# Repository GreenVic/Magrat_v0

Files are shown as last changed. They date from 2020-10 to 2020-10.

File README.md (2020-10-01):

# "Magrat" STM32H7 Board

NOTE: This is an early revision of a board which I am in the process of revising. I'm publishing the design files for the sake of sharing now that I've tested many (but not all) of the board's main features, but there are plenty of improvements which should be made, and you should not treat this as a solid reference implementation or a finalized production-ready design.

In particular, the SDRAM traces need better length- and impedance-matching; they seem to work up to 80-100MHz, but the chips are rated for 166MHz. The BOOT0 and JTAG signals should also be broken out, because the STM32H7's myriad clock domains seem to cause minor issues with SWD debugging.

With those disclaimers out of the way, "Magrat" is an STM32H7 board which aims to integrate enough external memory to run a minimal Linux system in a low-cost format. It is designed for single-sided PCA with parts from the LCSC catalog, so you should be able to order it 'as is' from JLCPCB when / if the parts are in stock.

This board should be able to run a mainline Linux kernel, and I've gotten one booting, but I'm still working on bringing up a fully-functional system, and I'm not quite sure that the microSD card socket works yet.

(TODO: add generated gerbers, BoM, pick-and-place files)

# Board Renders:

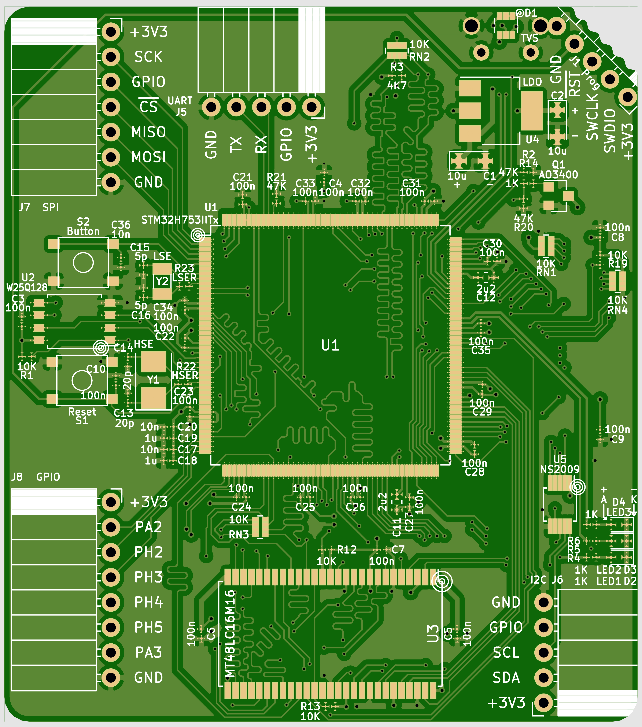
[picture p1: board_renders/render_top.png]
Board Top

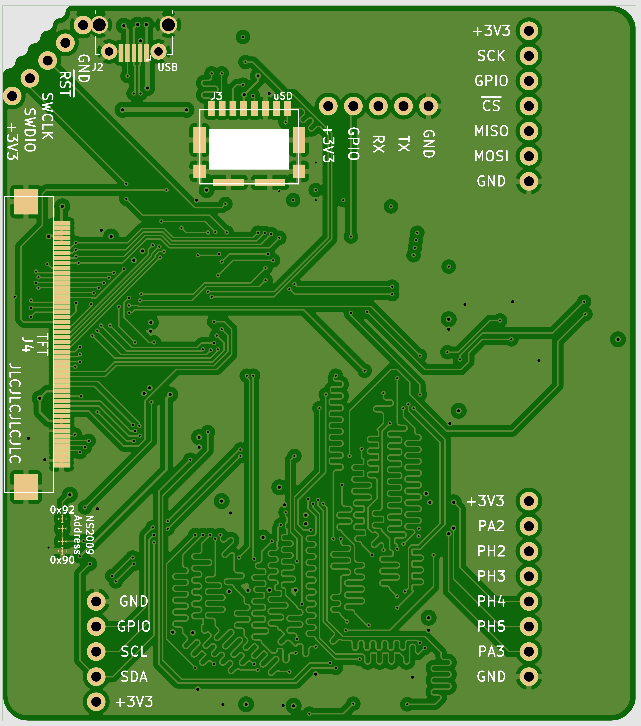
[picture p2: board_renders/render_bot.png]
Board Bottom


## Features

* STM32H7x3II: Cortex-M7, 480MHz, 2MiB Flash, 1MiB RAM

* 32MiB SDRAM

* 16MiB Quad-SPI Flash

* 50-pin ILI9341 display connector (untested)

* USB full-speed (untested)

* microSD card socket (untested)

* UART, SPI, I2C headers.

## (TODO: more explanation)

Test programs and a bit more information can be found in the `firmware/` directory.

They're a little rough-around-the-edges right now, because I haven't had these boards for long and it's my first time using an STM32H7 chip.

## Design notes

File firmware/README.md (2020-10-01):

# "Magrat" Board Test Programs

## Overview

These are a few basic test programs to communicate with the devices included on a first-revision STM32 SBC that I call a "Magrat".

I'm already planning a second revision with a few improvements:

* Better high-speed bus design. The 166-MHz SDRAM works, but it can't operate faster than 80MHz with the current design.
* Break out all of the JTAG pins, and BOOT0. SWD is not the best option for STM32H7 chips.
* Unify GPIOs into one or two headers.

The board includes:

* An STM32H743II or STM32H753II microcontroller
* 32MiB of SDRAM
* 16MiB of QSPI Flash
* microSD card socket
* 3 LEDs
* 1 button
* microUSB-B socket
* 50-pin FPC connector for an ILI9341 display
* NS2009 touch screen interface

And it has the following GPIO connectors:

* SPI
* UART
* I2C
* SWD
* 6 generic I/O pins

You can find the board design files in [TODO]. There is a KiCAD project, and a .zip archive containing PCB/PCA files in a format that JLCPCB (and probably other web-based PCA services) should accept.

Currently, the following tests are provided:

* leds\_test: Toggle the on-board LEDs.
* button\_test: Toggle the on-board LEDs when the user button is pressed.
* uart\_test: Test the UART interface by echoing data from `RX` to `TX`.
* sdram\_test: Test reading / writing external SDRAM, print results.
* qspi\_test: Test reading / writing on the external QSPI Flash chip.
* osc\_test: Test the HSE and LSE oscillators.
* mmc\_test: Test reading / writing data to a microSD card. (Overwrites existing data)
* linux\_bootloader: Simple bootloader program to initialize memory and start an XIP Linux kernel located in QSPI Flash.

## Board Recovery

It's much easier to soft-brick STM32H7s than simpler STM32 lines, so if you're using open-source tools, you might get into a situation where it is difficult to re-flash them. If that happens:

* Un-plug the board.

* Hold the reset button down.

* Plug the board in and open an OpenOCD connection while holding the reset button. Ignore the errors.

* Open a connection to OpenOCD (while still holding NRST low): `telnet localhost 4444`.

* Run `reset halt`, and release the reset button before the "halt" command times out.

* Run `stm32h7x mass_erase 0` to erase the offending application in Flash bank 0.

* Next time, consider adding a startup delay before your application does something potentially dicey. :)

I've had to do this a couple of times, but these chips are pretty resilient. Normally your debugger would take care of this process for you, but when you debug STM32H7 chips over SWD, the NRST pin can interfere with some debugging operations. It's broken the point that simply running `reset halt` crashes the chip! So when you design your own STM32H7 boards, you might want to expose all of the JTAG pins.

So this would be a bit easier with ST's closed-source tooling, but nobody likes a quitter...or a developer who uses Windows :P

## Pin Configurations

The following pinouts are used for GPIO connections. `NC` = Not Connected, and directional signal names are from the microcontroller's perspective:

| Pin | Function |
|---|---|
| PA0 | GPIO (UART header) |
| PA1 | Display (R2) |
| PA2 | GPIO (Marked on silkscreen) |
| PA3 | GPIO (Marked on silkscreen) |
| PA4 | `NC` |
| PA5 | `NC` |
| PA6 | `NC` |
| PA7 | SDRAM NWE |
| PA8 | Display (R6) |
| PA9 | Display (Tear Effect IRQ) |
| PA10  | USB ID |
| PA11  | USB D- |
| PA12  | USB D+ |
| PA13  | SWDIO (Debug) |
| PA14  | SWCLK (Debug) |
| PA15  | `NC` |
| PB0 | `NC` |
| PB1 | `NC` |
| PB2 | QSPI CLK |
| PB3 | `NC` |
| PB4 | `NC` |
| PB5 | `NC` |
| PB6 | QSPI NCS |
| PB7 | `NC` |
| PB8 | UART RX |
| PB9 | UART TX |
| PB10  | I2C SCL |
| PB11  | I2C SDA |
| PB12  | Display (SPI, NCS) |
| PB13  | Display (SPI, SCK) |
| PB14  | Display (SPI, SDI) |
| PB15  | Display (SPI, SDO) |
| PC0 | `NC` |
| PC1 | `NC` |
| PC2\_C | `NC` |
| PC3\_C | `NC` |
| PC4 | SDRAM SDNE0 |
| PC5 | SDRAM SDCKE0 |
| PC6 | LED2 |
| PC7 | LED3 |
| PC8 | SDMMC D0 |
| PC9 | SDMMC D1 |
| PC10  | SDMMC D2 |
| PC11  | SDMMC D3 |
| PC12  | SDMMC CLK |
| PC13  | Button1 |
| PC14  | 32.768KHz XTal in |
| PC15  | 32.768KHz XTal out |
| PD0 | SDRAM D2 |
| PD1 | SDRAM D3 |
| PD2 | SDMMC CMD |
| PD3 | Display (Mode select 0) |
| PD4 | Display (Mode select 1) |
| PD5 | Display (Mode select 2) |
| PD6 | Display (Mode select 3) |
| PD7 | `NC` |
| PD8 | SDRAM D13 |
| PD9 | SDRAM D14 |
| PD10  | SDRAM D15 |
| PD11  | NS2009 Touch input IRQ |
| PD12  | LED1 |
| PD13  | `NC` |
| PD14  | SDRAM D0 |
| PD15  | SDRAM D1 |
| PE0 | SDRAM NBL0 |
| PE1 | SDRAM NBL1 |
| PE2 | SPI SCK |
| PE3 | GPIO (SPI header) |
| PE4 | SPI NCS |
| PE5 | SPI SDI |
| PE6 | SPI SDO |
| PE7 | SDRAM D4 |
| PE8 | SDRAM D5 |
| PE9 | SDRAM D6 |
| PE10  | SDRAM D7 |
| PE11  | SDRAM D8 |
| PE12  | SDRAM D9 |
| PE13  | SDRAM D10 |
| PE14  | SDRAM D11 |
| PE15  | SDRAM D12 |
| PF0 | SDRAM A0 |
| PF1 | SDRAM A1 |
| PF2 | SDRAM A2 |
| PF3 | SDRAM A3 |
| PF4 | SDRAM A4 |
| PF5 | SDRAM A5 |
| PF6 | QSPI D3 |
| PF7 | QSPI D2 |
| PF8 | QSPI D0 |
| PF9 | QSPI D1 |
| PF10  | Display (Data enable) |
| PF11  | SDRAM (NRAS) |
| PF12  | SDRAM (A6) |
| PF13  | SDRAM (A7) |
| PF14  | SDRAM (A8) |
| PF15  | SDRAM (A9) |
| PG0 | SDRAM (A10) |
| PG1 | SDRAM (A11) |
| PG2 | SDRAM (A12) |
| PG3 | `NC` |
| PG4 | SDRAM (BA0) |
| PG5 | SDRAM (BA1) |
| PG6 | Display (R7) |
| PG7 | Display (Dot clock) |
| PG8 | SDRAM (CLK) |
| PG9 | `NC` |
| PG10  | Display (B2) |
| PG11  | Display (B3) |
| PG12  | `NC` |
| PG13  | `NC` |
| PG14  | `NC` |
| PG15  | SDRAM (NCAS) |
| PH0 | 8MHz XTal in |
| PH1 | 8MHz XTal out |
| PH2 | GPIO (Marked on silkscreen) |
| PH3 | GPIO (Marked on silkscreen) |
| PH4 | GPIO (Marked on silkscreen) |
| PH5 | GPIO (Marked on silkscreen) |
| PH6 | Display (PWM brightness control) |
| PH7 | GPIO (I2C header) |
| PH8 | Display (NRST) |
| PH9 | Display (R3) |
| PH10  | Display (R4) |
| PH11  | Display (R5) |
| PH12  | Display (Dat/Cmd) |
| PH13  | Display (G2) |
| PH14  | Display (G3) |
| PH15  | Display (G4) |
| PI0 | Display (G5) |
| PI1 | Display (G6) |
| PI2 | Display (G7) |
| PI3 | `NC` |
| PI4 | Display (B4) |
| PI5 | Display (B5) |
| PI6 | Display (B6) |
| PI7 | Display (B7) |
| PI8 | `NC` |
| PI9 | Display (VSYNC) |
| PI10  | Display (HSYNC) |
| PI11  | `NC` |

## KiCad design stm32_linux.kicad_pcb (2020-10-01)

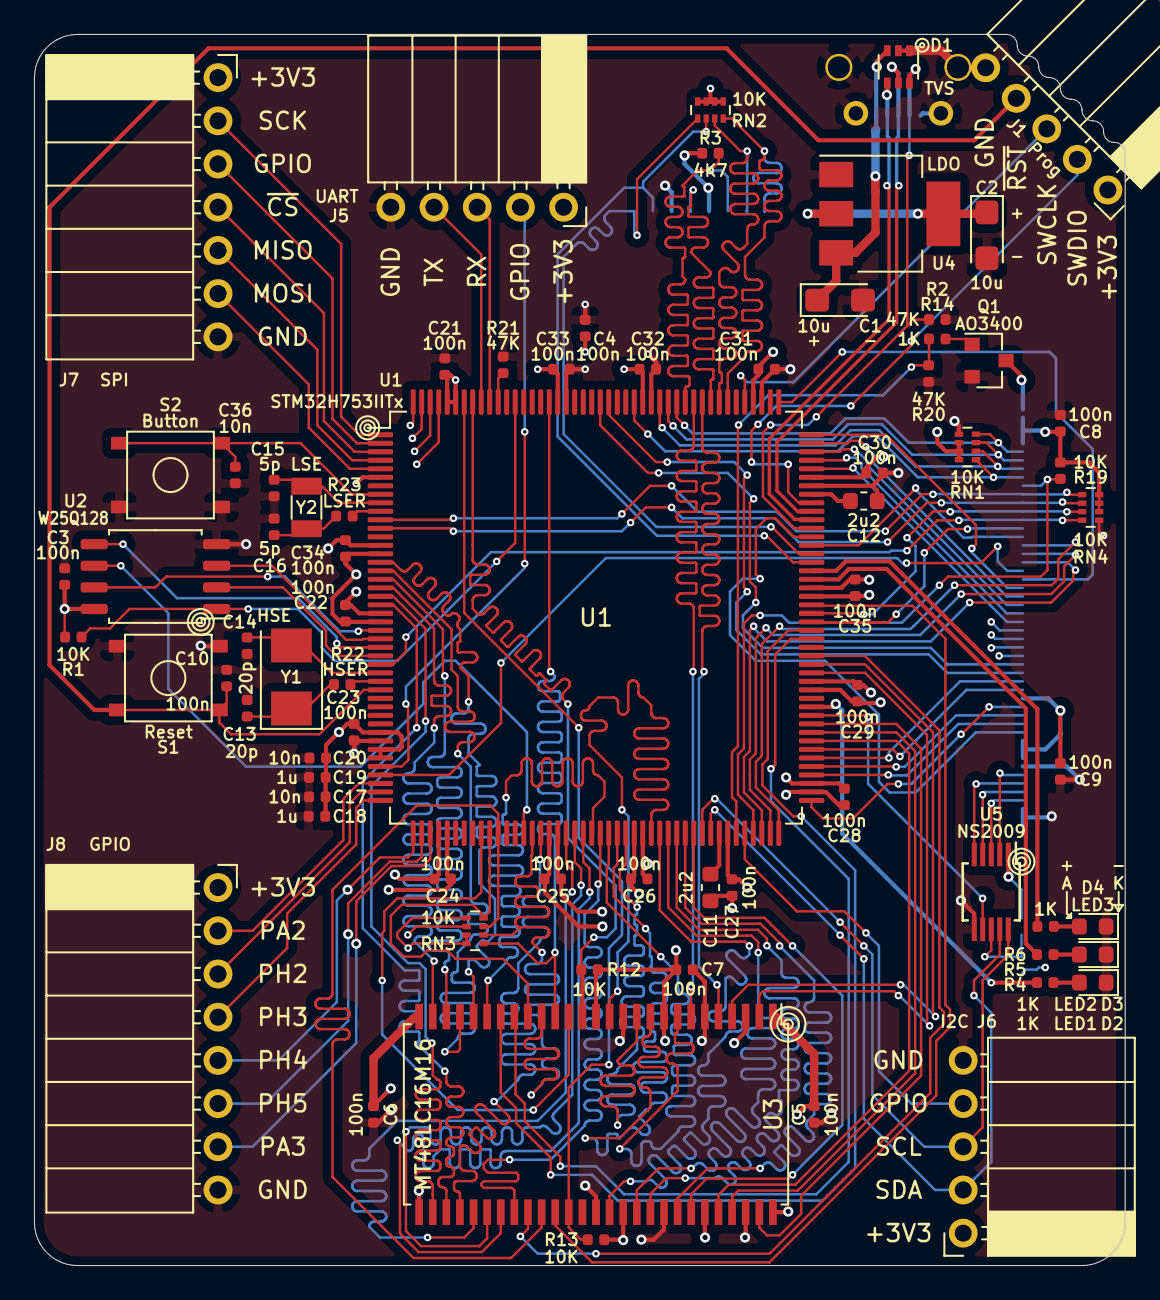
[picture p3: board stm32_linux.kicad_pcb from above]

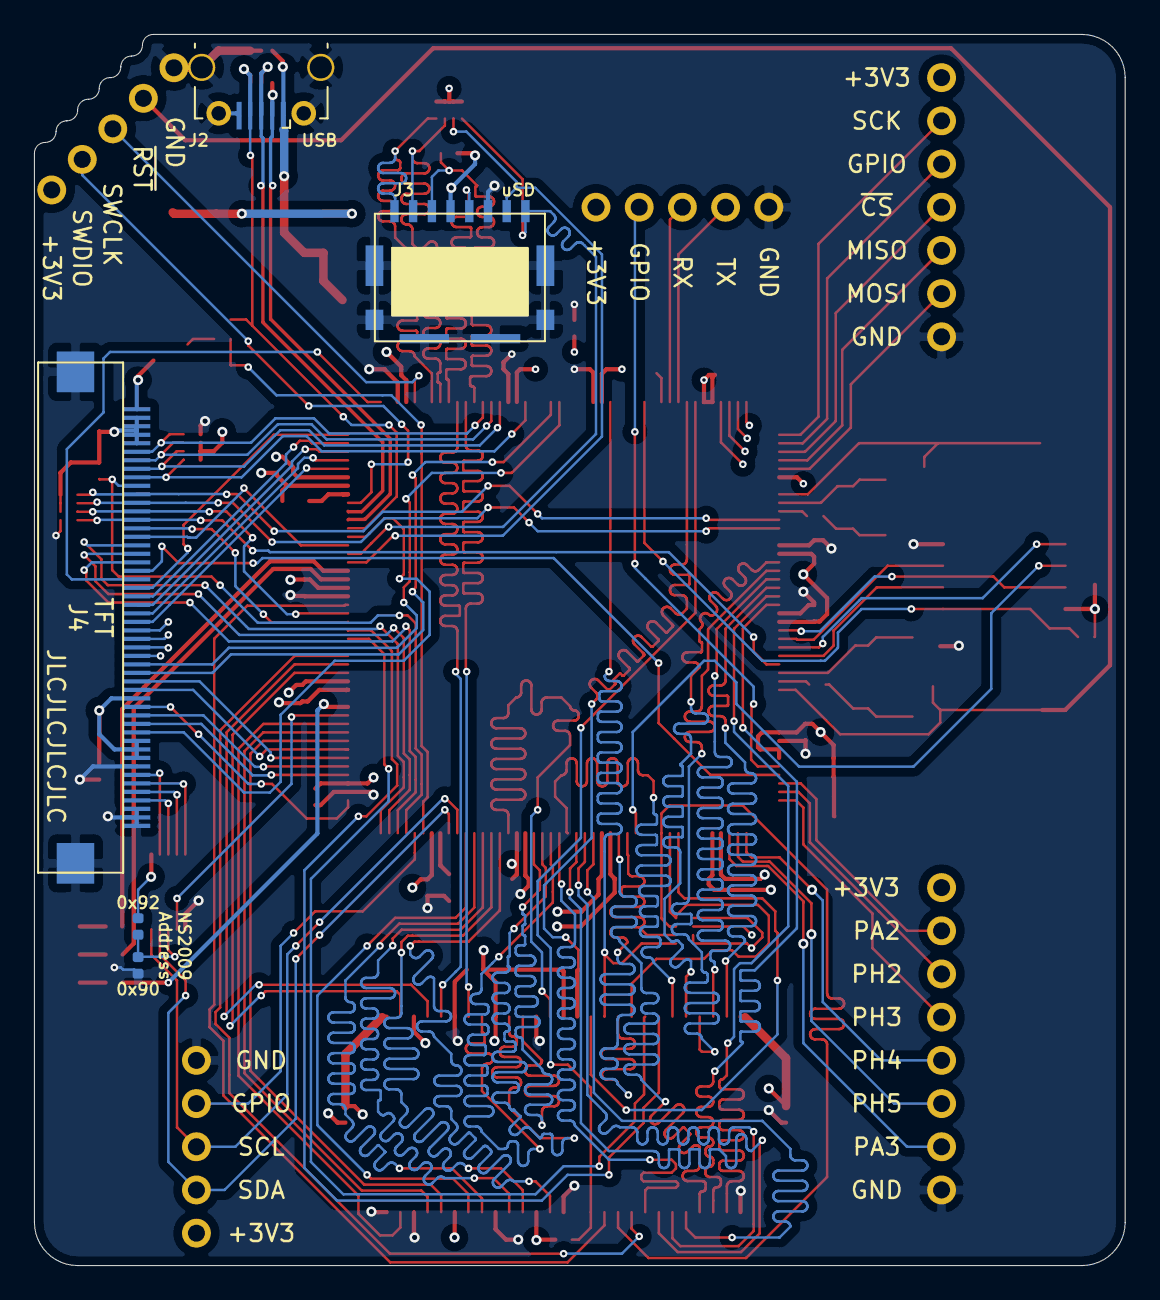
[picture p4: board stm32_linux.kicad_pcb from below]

Board: 4 copper layers, 64.1 x 72.4 mm, 78 parts (5 on the bottom side), 135 nets.

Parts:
C1, C2: 10u; CP_EIA-3216-10_Kemet-I
C3, C4, C5, C6, C7, C8, C9, C10, C21, C22, C23, C24, C25, C26, C27, C28, C29, C30, C31, C32, C33, C34, C35: 100n; C_0402_1005Metric
C11, C12: 2u2; C_0603_1608Metric
C13, C14: 20p; C_0402_1005Metric
C15, C16: 5p; C_0402_1005Metric
C17, C20, C36: 10n; C_0402_1005Metric
C18, C19: 1u; C_0402_1005Metric
D1: TVS; SOT-363_SC-70-6
D2: LED1; LED_0603_1608Metric
D3: LED2; LED_0603_1608Metric
D4: LED3; LED_0603_1608Metric
J1: Prog; PinSocket_1x05_P2.54mm_Horizontal
J2: USB; MyMicroUSB
J3: uSD; microSD_1051620001
J4: TFT; FPC_50p_0.5mm
J5: UART; PinSocket_1x05_P2.54mm_Horizontal
J6: I2C; PinSocket_1x05_P2.54mm_Horizontal
J7: SPI; PinSocket_1x07_P2.54mm_Horizontal
J8: GPIO; PinSocket_1x08_P2.54mm_Horizontal
Q1: AO3400; SOT-23
R1, R12, R13, R19: 10K; R_0402_1005Metric
R2, R20, R21: 47K; R_0402_1005Metric
R3: 4K7; R_0402_1005Metric
R4, R5, R6, R14: 1K; R_0402_1005Metric
R7: 0x92; R_0402_1005Metric
R8: 0x90; R_0402_1005Metric
R22: HSER; R_0402_1005Metric
R23: LSER; R_0402_1005Metric
RN1, RN2, RN3, RN4: 10K; R_Array_Concave_4x0402
S1: Reset; button_jlcpcb
S2: Button; button_jlcpcb
U1: STM32H753IITx; LQFP-176_24x24mm_P0.5mm
U2: W25Q128; SOIC-8_5.23x5.23mm_P1.27mm
U3: MT48LC16M16; TSOP-II-54_22.2x10.16mm_P0.8mm
U4: LDO; SOT-223-3_TabPin2
U5: NS2009; MSOP-10_3x3mm_P0.5mm
Y1: HSE; Crystal_SMD_5032-2Pin_5.0x3.2mm
Y2: LSE; Crystal_SMD_3215-2Pin_3.2x1.5mm

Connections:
+3V3: C2.1, C3.1, C4.1, C5.2, C6.2, C7.2, C8.1, C9.1, C17.2, C18.2, C19.2, C20.2, C21.2, C22.2, C23.2, C24.2, C25.2, C26.2, C27.2, C28.2, C29.2, C30.2, C31.2, C32.2, C33.2, C34.2, C35.2, J1.1, J3.4, J4.2, J4.3, J4.4, J4.5, J4.35, J4.40, J4.41, J4.42, J5.1, J6.1, J7.1, J8.1, R1.1, R3.1, R7.1, R12.2, R13.2, R19.1, RN1.2, RN1.3, RN1.4, RN2.5, RN2.6, RN2.7, RN2.8, RN3.5, RN3.7, RN3.8, RN4.6, RN4.7, RN4.8, U1.6, U1.15, U1.23, U1.36, U1.38, U1.39, U1.49, U1.62, U1.72, U1.82, U1.91, U1.103, U1.114, U1.127, U1.136, U1.149, U1.159, U1.171, U1.172, U2.8, U3.1, U3.3, U3.9, U3.14, U3.27, U3.43, U3.49, U4.2, U5.1
+5V: C1.1, D1.3, J2.1, U4.3
BTN1: C36.2, S2.1, U1.8
FMC_A0: U1.16, U3.23
FMC_A1: U1.17, U3.24
FMC_A2: U1.18, U3.25
FMC_A3: U1.19, U3.26
FMC_A4: U1.20, U3.29
FMC_A5: U1.21, U3.30
FMC_A6: U1.60, U3.31
FMC_A7: U1.63, U3.32
FMC_A8: U1.64, U3.33
FMC_A9: U1.65, U3.34
FMC_A10: U1.66, U3.22
FMC_A11: U1.67, U3.35
FMC_A12: U1.106, U3.36
FMC_BA0: U1.108, U3.20
FMC_BA1: U1.109, U3.21
FMC_D0: U1.104, U3.2
FMC_D1: U1.105, U3.4
FMC_D2: U1.142, U3.5
FMC_D3: U1.143, U3.7
FMC_D4: U1.68, U3.8
FMC_D5: U1.69, U3.10
FMC_D6: U1.70, U3.11
FMC_D7: U1.73, U3.13
FMC_D8: U1.74, U3.42
FMC_D9: U1.75, U3.44
FMC_D10: U1.76, U3.45
FMC_D11: U1.77, U3.47
FMC_D12: U1.78, U3.48
FMC_D13: U1.96, U3.50
FMC_D14: U1.97, U3.51
FMC_D15: U1.98, U3.53
FMC_NBL0: R12.1, U1.169, U3.15
FMC_NBL1: R13.1, U1.170, U3.39
FMC_NCAS: RN3.1, U1.160, U3.17
FMC_NRAS: RN3.2, U1.59, U3.18
FMC_SDCKE0: RN3.3, U1.55, U3.37
FMC_SDCLK: U1.112, U3.38
FMC_SDNE0: RN3.4, U1.54, U3.19
FMC_SDNWE: U1.53, U3.16
GND: C1.2, C2.2, C3.2, C4.2, C5.1, C6.1, C7.1, C8.2, C9.2, C10.2, C11.2, C12.2, C13.2, C14.1, C15.1, C16.1, C17.1, C18.1, C19.1, C20.1, C21.1, C22.1, C23.1, C24.1, C25.1, C26.1, C27.1, C28.1, C29.1, C30.1, C31.1, C32.1, C33.1, C34.1, C35.1, C36.1, D1.1, D1.2, D2.1, D3.1, D4.1, J1.5, J2.5, J2.6, J3.6, J3.9, J4.43, J4.48, J4.49, J4.50, J4.51, J5.5, J6.5, J7.7, J8.8, Q1.2, R2.1, R8.2, R20.2, R21.2, RN1.1, RN3.6, RN4.5, S1.1, S2.2, U1.14, U1.22, U1.37, U1.48, U1.61, U1.71, U1.90, U1.102, U1.113, U1.126, U1.135, U1.148, U1.158, U2.4, U3.6, U3.12, U3.28, U3.41, U3.46, U3.52, U3.54, U4.1, U5.6
I2C_ETC: J6.4, U1.84
I2C_SCL: J6.3, U1.79, U5.10
I2C_SDA: J6.2, U1.80, U5.9
LED1: R4.2, U1.100
LED2: R5.2, U1.115
LED3: R6.2, U1.116
MMC_CLK: J3.5, U1.141
MMC_CMD: J3.3, R3.2, U1.144
MMC_D0: J3.7, RN2.2, U1.117
MMC_D1: J3.8, RN2.1, U1.118
MMC_D2: J3.1, RN2.4, U1.139
MMC_D3: J3.2, RN2.3, U1.140
unnamed: C11.1, U1.81
unnamed: C12.1, U1.125
unnamed: C13.1, R22.2, Y1.1
unnamed: C14.2, U1.29, Y1.2
unnamed: C15.2, U1.9, Y2.1
unnamed: C16.2, R23.1, Y2.2
unnamed: D2.2, R4.1
unnamed: D3.2, R5.1
unnamed: D4.2, R6.1
unnamed: J4.1, Q1.3
unnamed: Q1.1, R14.1
unnamed: R7.2, R8.1, U5.8
unnamed: R21.1, U1.166
unnamed: R22.1, U1.30
unnamed: R23.2, U1.10
PA2: J8.2, U1.42
PA3: J8.7, U1.47
PH2: J8.3, U1.43
PH3: J8.4, U1.44
PH4: J8.5, U1.45
PH5: J8.6, U1.46
QSPI_CLK: U1.58, U2.6
QSPI_D0: U1.26, U2.5
QSPI_D1: U1.27, U2.2
QSPI_D2: U1.25, U2.3
QSPI_D3: U1.24, U2.7
QSPI_~CS: R1.2, U1.164, U2.1
RST: C10.1, J1.4, S1.2, U1.31
SPI_ETC: J7.3, U1.2
SPI_MISO: J7.5, U1.4
SPI_MOSI: J7.6, U1.5
SPI_SCK: J7.2, U1.1
SPI_~CS: J7.4, U1.3
SWCLK: J1.3, U1.137
SWDIO: J1.2, U1.124
TFT_B2: J4.32, U1.153
TFT_B3: J4.31, U1.154
TFT_B4: J4.30, U1.173
TFT_B5: J4.29, U1.174
TFT_B6: J4.28, U1.175
TFT_B7: J4.27, U1.176
TFT_D6: J4.26, U1.128
TFT_D7: J4.25, U1.129
TFT_D8: J4.24, U1.130
TFT_D9: J4.23, U1.131
TFT_D10: J4.22, U1.132
TFT_D11: J4.21, U1.133
TFT_D12: J4.20, U1.41
TFT_D13: J4.19, U1.86
TFT_D14: J4.18, U1.87
TFT_D15: J4.17, U1.88
TFT_D16: J4.16, U1.119
TFT_D17: J4.15, U1.110
TFT_DC: J4.36, U1.89
TFT_DE: J4.14, RN4.4, U1.28
TFT_DOTCLK: J4.13, RN4.3, U1.111
TFT_HSYNC: J4.12, RN4.2, U1.12
TFT_IM0: J4.6, RN1.8, U1.145
TFT_IM1: J4.7, RN1.7, U1.146
TFT_IM2: J4.8, RN1.6, U1.147
TFT_IM3: J4.9, RN1.5, U1.150
TFT_MISO: J4.33, U1.94
TFT_MOSI: J4.34, U1.95
TFT_PWM: R14.2, R20.1, U1.83
TFT_RST: J4.10, R19.2, U1.85
TFT_SCK: J4.37, U1.93
TFT_TE: J4.39, U1.120
TFT_VSYNC: J4.11, RN4.1, U1.11
TFT_XL: J4.46, U5.4
TFT_XR: J4.44, U5.2
TFT_YD: J4.45, U5.5
TFT_YU: J4.47, U5.3
TFT_~CS: J4.38, U1.92
TIRQ: U1.99, U5.7
UART_ETC: J5.2, U1.40
UART_RX: J5.3, U1.167
UART_TX: J5.4, U1.168
USB_D+: D1.5, J2.3, U1.123
USB_D-: D1.4, J2.2, U1.122
USB_ID: D1.6, J2.4, R2.2, U1.121

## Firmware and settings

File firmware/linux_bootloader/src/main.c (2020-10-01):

#include "global.h"
#include "qspi.h"

// Core system clock speed.
uint32_t SystemCoreClock = 64000000;
// Global systick counter.
volatile uint32_t systick = 0;

// Reset handler: set the stack pointer and branch to main().
__attribute__( ( naked ) ) void reset_handler( void ) {
  // Set the stack pointer to the 'end of stack' value.
  __asm__( "LDR r0, =_estack\n\t"
           "MOV sp, r0" );
  // Branch to main().
  __asm__( "B main" );
}

/**
 * Main program.
 */
int main( void ) {
  RCC->D3AMR = 0xFFFFFFFF;
  RCC->AHB1ENR = 0xFFFFFFFF;
  RCC->AHB2ENR = 0xFFFFFFFF;
  RCC->AHB3ENR = 0xFFFFFFFF;
  RCC->AHB4ENR = 0xFFFFFFFF;
  RCC->APB1LENR = 0xFFFFFFFF;
  RCC->APB1HENR = 0xFFFFFFFF;
  RCC->APB2ENR = 0xFFFFFFFF;
  RCC->APB3ENR = 0xFFFFFFFF;
  RCC->APB4ENR = 0xFFFFFFFF;
  /*
  // TODO: Enable SRAM1, SRAM2, SRAM3.
  // Enable GPIOA, GPIOB, GPIOC, GPIOD, GPIOE, GPIOF, GPIOG,
  // FMC, QSPI, SDMMC1, and UART4 peripherals.
  RCC->AHB3ENR  |=  ( RCC_AHB3ENR_FMCEN |
                      RCC_AHB3ENR_QSPIEN |
                      RCC_AHB3ENR_SDMMC1EN );
  RCC->AHB4ENR  |=  ( RCC_AHB4ENR_GPIOAEN |
                      RCC_AHB4ENR_GPIOBEN |
                      RCC_AHB4ENR_GPIOCEN |
                      RCC_AHB4ENR_GPIODEN |
                      RCC_AHB4ENR_GPIOEEN |
                      RCC_AHB4ENR_GPIOFEN |
                      RCC_AHB4ENR_GPIOGEN );
  RCC->APB1LENR |=  ( RCC_APB1LENR_UART4EN );
  */

  // Copy initialized data from .sidata (Flash) to .data (RAM)
  memcpy( &_sdata, &_sidata, ( ( void* )&_edata - ( void* )&_sdata ) );
  memcpy( &_sitcm, &_siitcm, ( ( void* )&_eitcm - ( void* )&_sitcm ) );
  memcpy( &_sdtcm, &_sidtcm, ( ( void* )&_edtcm - ( void* )&_sdtcm ) );
  // Clear the .bss section in RAM.
  memset( &_sbss, 0x00, ( ( void* )&_ebss - ( void* )&_sbss ) );

  // Enable floating-point unit.
  SCB->CPACR      |=  ( 0xF << 20 );

  // Set PLL1 'P' clock speed to 480MHz = ( 64MHz * ( N / M ) / P ).
  // But ( 64MHz / M ) <= 2Mhz, so P = 1, M = 32, N = 240.
  // Or, for 240MHz, M = 32, N = 64, P = 2
  // First, enable the PLL1_P output and set HSI as clock input.
  RCC->PLLCKSELR  &= ~( RCC_PLLCKSELR_PLLSRC | RCC_PLLCKSELR_DIVM1 );
  RCC->PLLCKSELR  |=  ( 32 << RCC_PLLCKSELR_DIVM1_Pos );
  // Set 4 wait states in Flash with a 'programming delay' of 2.
  FLASH->ACR       =  ( ( 5 << FLASH_ACR_LATENCY_Pos ) |
                        ( 2 << FLASH_ACR_WRHIGHFREQ_Pos ) );
  // Set the PLL1 dividers register.
  RCC->PLL1DIVR   &= ~( RCC_PLL1DIVR_N1 | RCC_PLL1DIVR_P1 );
  //RCC->PLL1DIVR   |=  ( 129 << RCC_PLL1DIVR_N1_Pos );
  RCC->PLL1DIVR   |=  ( 239 << RCC_PLL1DIVR_N1_Pos |
                        1 << RCC_PLL1DIVR_P1_Pos );
  // Enable the PLL and wait for it to be ready.
  RCC->CR         |=  ( RCC_CR_PLL1ON );
  while( !( RCC->CR & RCC_CR_PLL1RDY ) ) {};
  // Switch to the PLL as the main clock source.
  RCC->CFGR       |=  ( RCC_CFGR_SW_PLL1 );
  while( ( RCC->CFGR & RCC_CFGR_SWS ) != RCC_CFGR_SWS_PLL1 ) {};
  // Clock speed is now 240MHz.
  SystemCoreClock  = 240000000;

  // Set UART pins (B8, B9) to alt. func. 8, medium-speed.
  GPIOB->MODER    &= ~( ( 3 << ( 8 * 2 ) ) | ( 3 << ( 9 * 2 ) ) );
  GPIOB->MODER    |=  ( ( 2 << ( 8 * 2 ) ) | ( 2 << ( 9 * 2 ) ) );
  GPIOB->OSPEEDR  |=  ( ( 1 << ( 8 * 2 ) ) | ( 1 << ( 9 * 2 ) ) );
  GPIOB->AFR[ 1 ] |=  ( ( 8 << ( ( 8 - 8 ) * 4 ) ) |
                        ( 8 << ( ( 9 - 8 ) * 4 ) ) );

  // Set SDRAM pins to high-speed alt. func. mode.
  GPIOA->MODER    &= ~( 3 << ( 7 * 2 ) );
  GPIOA->MODER    |=  ( 2 << ( 7 * 2 ) );
  GPIOA->OSPEEDR  |=  ( 3 << ( 7 * 2 ) );
  GPIOA->AFR[ 0 ] |=  ( 12 << ( 7 * 4 ) );
  GPIOC->MODER    &= ~( ( 3 << ( 4 * 2 ) ) | ( 3 << ( 5 * 2 ) ) );
  GPIOC->MODER    |=  ( ( 2 << ( 4 * 2 ) ) | ( 2 << ( 5 * 2 ) ) );
  GPIOC->OSPEEDR  |=  ( ( 3 << ( 4 * 2 ) ) | ( 3 << ( 5 * 2 ) ) );
  GPIOC->AFR[ 0 ] |=  ( ( 12 << ( 4 * 4 ) ) | ( 12 << ( 5 * 4 ) ) );
  GPIOD->MODER    &= ~( ( 3 << ( 0 * 2 ) ) | ( 3 << ( 1 * 2 ) ) |
                        ( 3 << ( 8 * 2 ) ) | ( 3 << ( 9 * 2 ) ) |
                        ( 3 << ( 10 * 2 ) ) | ( 3 << ( 14 * 2 ) ) |
                        ( 3 << ( 15 * 2 ) ) );
  GPIOD->MODER    |=  ( ( 2 << ( 0 * 2 ) ) | ( 2 << ( 1 * 2 ) ) |
                        ( 2 << ( 8 * 2 ) ) | ( 2 << ( 9 * 2 ) ) |
                        ( 2 << ( 10 * 2 ) ) | ( 2 << ( 14 * 2 ) ) |
                        ( 2 << ( 15 * 2 ) ) );
  GPIOD->OSPEEDR  |=  ( ( 3 << ( 0 * 2 ) ) | ( 3 << ( 1 * 2 ) ) |
                        ( 3 << ( 8 * 2 ) ) | ( 3 << ( 9 * 2 ) ) |
                        ( 3 << ( 10 * 2 ) ) | ( 3 << ( 14 * 2 ) ) |
                        ( 3 << ( 15 * 2 ) ) );
  GPIOD->AFR[ 0 ] |=  ( ( 12 << ( 0 * 4 ) ) | ( 12 << ( 1 * 4 ) ) );
  GPIOD->AFR[ 1 ] |=  ( ( 12 << ( ( 8 - 8 ) * 4 ) ) |
                        ( 12 << ( ( 9 - 8 ) * 4 ) ) |
                        ( 12 << ( ( 10 - 8 ) * 4 ) ) |
                        ( 12 << ( ( 14 - 8 ) * 4 ) ) |
                        ( 12 << ( ( 15 - 8 ) * 4 ) ) );
  GPIOE->MODER    &= ~( ( 3 << ( 0 * 2 ) ) | ( 3 << ( 1 * 2 ) ) |
                        ( 3 << ( 7 * 2 ) ) | ( 3 << ( 8 * 2 ) ) |
                        ( 3 << ( 9 * 2 ) ) | ( 3 << ( 10 * 2 ) ) |
                        ( 3 << ( 11 * 2 ) ) | ( 3 << ( 12 * 2 ) ) |
                        ( 3 << ( 13 * 2 ) ) | ( 3 << ( 14 * 2 ) ) |
                        ( 3 << ( 15 * 2 ) ) );
  GPIOE->MODER    |=  ( ( 2 << ( 0 * 2 ) ) | ( 2 << ( 1 * 2 ) ) |
                        ( 2 << ( 7 * 2 ) ) | ( 2 << ( 8 * 2 ) ) |
                        ( 2 << ( 9 * 2 ) ) | ( 2 << ( 10 * 2 ) ) |
                        ( 2 << ( 11 * 2 ) ) | ( 2 << ( 12 * 2 ) ) |
                        ( 2 << ( 13 * 2 ) ) | ( 2 << ( 14 * 2 ) ) |
                        ( 2 << ( 15 * 2 ) ) );
  GPIOE->OSPEEDR  |=  ( ( 3 << ( 0 * 2 ) ) | ( 3 << ( 1 * 2 ) ) |
                        ( 3 << ( 7 * 2 ) ) | ( 3 << ( 8 * 2 ) ) |
                        ( 3 << ( 9 * 2 ) ) | ( 3 << ( 10 * 2 ) ) |
                        ( 3 << ( 11 * 2 ) ) | ( 3 << ( 12 * 2 ) ) |
                        ( 3 << ( 13 * 2 ) ) | ( 3 << ( 14 * 2 ) ) |
                        ( 3 << ( 15 * 2 ) ) );
  GPIOE->AFR[ 0 ] |=  ( ( 12 << ( 0 * 4 ) ) | ( 12 << ( 1 * 4 ) ) |
                        ( 12 << ( 7 * 4 ) ) );
  GPIOE->AFR[ 1 ] |=  ( ( 12 << ( ( 8 - 8 ) * 4 ) ) |
                        ( 12 << ( ( 9 - 8 ) * 4 ) ) |
                        ( 12 << ( ( 10 - 8 ) * 4 ) ) |
                        ( 12 << ( ( 11 - 8 ) * 4 ) ) |
                        ( 12 << ( ( 12 - 8 ) * 4 ) ) |
                        ( 12 << ( ( 13 - 8 ) * 4 ) ) |
                        ( 12 << ( ( 14 - 8 ) * 4 ) ) |
                        ( 12 << ( ( 15 - 8 ) * 4 ) ) );
  GPIOF->MODER    &= ~( ( 3 << ( 0 * 2 ) ) | ( 3 << ( 1 * 2 ) ) |
                        ( 3 << ( 2 * 2 ) ) | ( 3 << ( 3 * 2 ) ) |
                        ( 3 << ( 4 * 2 ) ) | ( 3 << ( 5 * 2 ) ) |
                        ( 3 << ( 11 * 2 ) ) | ( 3 << ( 12 * 2 ) ) |
                        ( 3 << ( 13 * 2 ) ) | ( 3 << ( 14 * 2 ) ) |
                        ( 3 << ( 15 * 2 ) ) );
  GPIOF->MODER    |=  ( ( 2 << ( 0 * 2 ) ) | ( 2 << ( 1 * 2 ) ) |
                        ( 2 << ( 2 * 2 ) ) | ( 2 << ( 3 * 2 ) ) |
                        ( 2 << ( 4 * 2 ) ) | ( 2 << ( 5 * 2 ) ) |
                        ( 2 << ( 11 * 2 ) ) | ( 2 << ( 12 * 2 ) ) |
                        ( 2 << ( 13 * 2 ) ) | ( 2 << ( 14 * 2 ) ) |
                        ( 2 << ( 15 * 2 ) ) );
  GPIOF->OSPEEDR  |=  ( ( 3 << ( 0 * 2 ) ) | ( 3 << ( 1 * 2 ) ) |
                        ( 3 << ( 2 * 2 ) ) | ( 3 << ( 3 * 2 ) ) |
                        ( 3 << ( 4 * 2 ) ) | ( 3 << ( 5 * 2 ) ) |
                        ( 3 << ( 11 * 2 ) ) | ( 3 << ( 12 * 2 ) ) |
                        ( 3 << ( 13 * 2 ) ) | ( 3 << ( 14 * 2 ) ) |
                        ( 3 << ( 15 * 2 ) ) );
  GPIOF->AFR[ 0 ] |=  ( ( 12 << ( 0 * 4 ) ) | ( 12 << ( 1 * 4 ) ) |
                        ( 12 << ( 2 * 4 ) ) | ( 12 << ( 3 * 4 ) ) |
                        ( 12 << ( 4 * 4 ) ) | ( 12 << ( 5 * 4 ) ) );
  GPIOF->AFR[ 1 ] |=  ( ( 12 << ( ( 11 - 8 ) * 4 ) ) |
                        ( 12 << ( ( 12 - 8 ) * 4 ) ) |
                        ( 12 << ( ( 13 - 8 ) * 4 ) ) |
                        ( 12 << ( ( 14 - 8 ) * 4 ) ) |
                        ( 12 << ( ( 15 - 8 ) * 4 ) ) );
  GPIOG->MODER    &= ~( ( 3 << ( 0 * 2 ) ) | ( 3 << ( 1 * 2 ) ) |
                        ( 3 << ( 2 * 2 ) ) | ( 3 << ( 4 * 2 ) ) |
                        ( 3 << ( 5 * 2 ) ) | ( 3 << ( 8 * 2 ) ) |
                        ( 3 << ( 15 * 2 ) ) );
  GPIOG->MODER    |=  ( ( 2 << ( 0 * 2 ) ) | ( 2 << ( 1 * 2 ) ) |
                        ( 2 << ( 2 * 2 ) ) | ( 2 << ( 4 * 2 ) ) |
                        ( 2 << ( 5 * 2 ) ) | ( 2 << ( 8 * 2 ) ) |
                        ( 2 << ( 15 * 2 ) ) );
  GPIOG->OSPEEDR  |=  ( ( 3 << ( 0 * 2 ) ) | ( 3 << ( 1 * 2 ) ) |
                        ( 3 << ( 2 * 2 ) ) | ( 3 << ( 4 * 2 ) ) |
                        ( 3 << ( 5 * 2 ) ) | ( 3 << ( 8 * 2 ) ) |
                        ( 3 << ( 15 * 2 ) ) );
  GPIOG->AFR[ 0 ] |=  ( ( 12 << ( 0 * 4 ) ) | ( 12 << ( 1 * 4 ) ) |
                        ( 12 << ( 2 * 4 ) ) | ( 12 << ( 4 * 4 ) ) |
                        ( 12 << ( 5 * 4 ) ) );
  GPIOG->AFR[ 1 ] |=  ( ( 12 << ( ( 8 - 8 ) * 4 ) ) |
                        ( 12 << ( ( 15 - 8 ) * 4 ) ) );

  // Set QSPI pins (B2, B6, F6-9) to high-speed alt. func. mode.
  GPIOB->MODER    &= ~( ( 3 << ( 2 * 2 ) ) | ( 3 << ( 6 * 2 ) ) );
  GPIOB->MODER    |=  ( ( 2 << ( 2 * 2 ) ) | ( 2 << ( 6 * 2 ) ) );
  GPIOB->OSPEEDR  |=  ( ( 3 << ( 2 * 2 ) ) | ( 3 << ( 6 * 2 ) ) );
  GPIOB->AFR[ 0 ] |=  ( ( 9 << ( 2 * 4 ) ) | ( 10 << ( 6 * 4 ) ) );
  GPIOF->MODER    &= ~( ( 3 << ( 6 * 2 ) ) | ( 3 << ( 7 * 2 ) ) |
                        ( 3 << ( 8 * 2 ) ) | ( 3 << ( 9 * 2 ) ) );
  GPIOF->MODER    |=  ( ( 2 << ( 6 * 2 ) ) | ( 2 << ( 7 * 2 ) ) |
                        ( 2 << ( 8 * 2 ) ) | ( 2 << ( 9 * 2 ) ) );
  GPIOF->OSPEEDR  |=  ( ( 3 << ( 6 * 2 ) ) | ( 3 << ( 7 * 2 ) ) |
                        ( 3 << ( 8 * 2 ) ) | ( 3 << ( 9 * 2 ) ) );
  GPIOF->PUPDR    |=  ( ( 1 << ( 6 * 2 ) ) | ( 1 << ( 7 * 2 ) ) );
  GPIOF->AFR[ 0 ] |=  ( ( 9 << ( 6 * 4 ) ) | ( 9 << ( 7 * 4 ) ) );
  GPIOF->AFR[ 1 ] |=  ( ( 10 << ( ( 8 - 8 ) * 4 ) ) |
                        ( 10 << ( ( 9 - 8 ) * 4 ) ) );

  // Enable the UART4 peripheral.
  UART4->BRR       =  ( SystemCoreClock / 115200 );
  UART4->CR1      |=  ( USART_CR1_UE | USART_CR1_TE | USART_CR1_RE );

  // Enable the FMC peripheral.
  FMC_Bank1_R->BTCR[ 0 ]    |=  ( FMC_BCR1_FMCEN );

  // Remap SDRAM1 to 0x60000000.
  FMC_Bank1_R->BTCR[ 0 ]    |=  ( 1 << FMC_BCR1_BMAP_Pos );

  // Enable the SDRAM bank in the FMC peripheral.
  // FMC Bank 5, SDRAM1 Bank 0 = MT48LC16M16A2
  // Control Register (see datasheet for these values):
  //   * 16-bit memory width.
  //   * 9 column address bits.
  //   * 13 row address bits.
  //   * 4 internal banks.
  //   * 2 cycles of CAS latency.
  //   * Writes enabled.
  //   * SDCLK = SYSCLK * 2
  FMC_Bank5_6_R->SDCR[ 0 ]  =  ( ( 1 << FMC_SDCRx_NC_Pos ) |
                                 ( 2 << FMC_SDCRx_NR_Pos ) |
                                 ( 1 << FMC_SDCRx_MWID_Pos ) |
                                 ( FMC_SDCRx_NB ) |
                                 ( 2 << FMC_SDCRx_CAS_Pos ) |
                                 ( 3 << FMC_SDCRx_SDCLK_Pos ) );

  // Timing Register:
  // At 240MHz / 2, one clock cycle = 8.33ns. @480MHz/3, 6.25ns.
  // CAS Latency: 18ns (configured in SDCR)
  // Row-to-column delay: 18ns
  // Row precharge delay: 18ns
  // Recovery delay: 2 cycles
  // Row cycle delay: 67ns
  // Self refresh time: 42ns
  // Exit self-refresh delay: 67ns
  // "Load mode register" to active delay: 2 cycles
  FMC_Bank5_6_R->SDTR[ 0 ]  =  ( ( 2 << FMC_SDTRx_TMRD_Pos ) |
                                 ( 8 << FMC_SDTRx_TXSR_Pos ) |
                                 ( 5 << FMC_SDTRx_TRAS_Pos ) |
                                 ( 8 << FMC_SDTRx_TRC_Pos ) |
                                 ( 2 << FMC_SDTRx_TWR_Pos ) |
                                 ( 2 << FMC_SDTRx_TRP_Pos ) |
                                 ( 2 << FMC_SDTRx_TRCD_Pos ) );
  //FMC_Bank5_6_R->SDTR[ 0 ]  =  0xFFFFFFFF;

  // Configrue 'target bank' bits in SDCMR, and
  // set SDCMR 'MODE' bits to 1 to start the SDRAM clock.
  /*
  FMC_Bank5_6_R->SDCMR     |=  ( FMC_SDCMR_CTB1 );
  FMC_Bank5_6_R->SDCMR     |=  ( 1 << FMC_SDCMR_MODE_Pos );
  */
  FMC_Bank5_6_R->SDCMR     =  ( ( 1 << FMC_SDCMR_MODE_Pos ) |
                                FMC_SDCMR_CTB1 );

  // Wait at least 100us for the SDRAM power-up delay.
  for ( int i = 0; i < 100000; ++i ) { __asm__( "nop" ); }

  // Wait for the undocumented 'busy' bit to clear.
  while( FMC_Bank5_6_R->SDSR & 0x00000020 ) {};

  // Set 'MODE' bits to 2 to issue a 'precharge all' command.
  /*
  FMC_Bank5_6_R->SDCMR     &= ~( FMC_SDCMR_MODE );
  FMC_Bank5_6_R->SDCMR     |=  ( 2 << FMC_SDCMR_MODE_Pos );
  */
  FMC_Bank5_6_R->SDCMR     =  ( ( 2 << FMC_SDCMR_MODE_Pos ) |
                                FMC_SDCMR_CTB1 );

  // Wait for the undocumented 'busy' bit to clear.
  while( FMC_Bank5_6_R->SDSR & 0x00000020 ) {};

  // Set 'MODE' bits to 3 and set # of consecutive auto-refreshes (2).
  /*
  //FMC_Bank5_6_R->SDCMR     |=  ( 1 << FMC_SDCMR_NRFS_Pos );
  FMC_Bank5_6_R->SDCMR     |=  ( 7 << FMC_SDCMR_NRFS_Pos );
  FMC_Bank5_6_R->SDCMR     &= ~( FMC_SDCMR_MODE );
  FMC_Bank5_6_R->SDCMR     |=  ( 3 << FMC_SDCMR_MODE_Pos );
  */
  FMC_Bank5_6_R->SDCMR     =  ( ( 1 << FMC_SDCMR_NRFS_Pos ) |
                                ( 3 << FMC_SDCMR_MODE_Pos ) |
                                FMC_SDCMR_CTB1 );

  // Wait for the undocumented 'busy' bit to clear.
  while( FMC_Bank5_6_R->SDSR & 0x00000020 ) {};

  // Send 'Load Mode Register' command.
  //   * Burst length: 1
  //   * Burst type: Sequential
  //   * CAS latency: 2 cycles
  //   * Operating mode: Standard
  //   * Write burst: Same as read
  //FMC_Bank5_6_R->SDCMR     |=  ( 0x020 << FMC_SDCMR_MRD_Pos );
  //FMC_Bank5_6_R->SDCMR     &= ~( FMC_SDCMR_MODE );
  //FMC_Bank5_6_R->SDCMR     |=  ( 4 << FMC_SDCMR_MODE_Pos );
  FMC_Bank5_6_R->SDCMR     =  ( ( 0x020 << FMC_SDCMR_MRD_Pos ) |
                                ( 4 << FMC_SDCMR_MODE_Pos ) |
                                FMC_SDCMR_CTB1 );

  // Wait for the undocumented 'busy' bit to clear.
  while( FMC_Bank5_6_R->SDSR & 0x00000020 ) {};

  // Configure SDRTR Refresh Timing Register:
  // 7.8us * 120MHz - 20 = 916.
  FMC_Bank5_6_R->SDRTR     |=  ( 916 << FMC_SDRTR_COUNT_Pos );

  // Make sure writes are enabled.
  FMC_Bank5_6_R->SDCR[ 0 ] &= ~( FMC_SDCRx_WP );

  // QSPI peripheral setup.
  // Flash size: 16MiB = 2^(23+1) bytes.
  QUADSPI->DCR    |=  ( 23 << QUADSPI_DCR_FSIZE_Pos );
  // Set 24-bit addressing.
  QUADSPI->CCR    |=  ( 2 << QUADSPI_CCR_ADSIZE_Pos );
  // Set clock prescaler to 240 / ( 2 + 1 ) = 80MHz.
  QUADSPI->CR     |=  ( ( 64 << QUADSPI_CR_PRESCALER_Pos ) |
                        QUADSPI_CR_SSHIFT );

  // Send 'enable writes' command.
  qspi_wen( 1 );

  // Wait for the 'write enable latch' to be set.
  qspi_reg_wait( 0x05, 0x03, 0x02, 1 );

  // Send 'write volatile status register 2' to 0x02.
  // Clear instruction, mode and transaction phases.
  QUADSPI->CCR  &= ~( QUADSPI_CCR_INSTRUCTION | QUADSPI_CCR_FMODE |
                      QUADSPI_CCR_IMODE | QUADSPI_CCR_DMODE |
                      QUADSPI_CCR_ADMODE );
  // Set 1-wire instruction and data modes, and auto-polling mode.
  QUADSPI->CCR  |=  ( ( 1 << QUADSPI_CCR_IMODE_Pos ) |
                      ( 1 << QUADSPI_CCR_DMODE_Pos ) );
  // Enable the peripheral.
  QUADSPI->CR   |=  ( QUADSPI_CR_EN );
  // Send information.
  QUADSPI->CCR  |=  ( 0x31 << QUADSPI_CCR_INSTRUCTION_Pos );
  QUADSPI->DR    =  ( 0x02 );
  // Wait for the transaction to finish.
  while ( QUADSPI->SR & QUADSPI_SR_BUSY ) {};
  // Disable the peripheral.
  QUADSPI->CR   &= ~( QUADSPI_CR_EN );

  // Wait for the register write to finish.
  qspi_reg_wait( 0x05, 0x01, 0x00, 1 );

  // Make sure that QSPI mode is enabled.
  qspi_reg_wait( 0x35, 0x02, 0x02, 1 );

  // Test external Flash reads.
  QUADSPI->CCR  &= ~( QUADSPI_CCR_INSTRUCTION | QUADSPI_CCR_FMODE |
                      QUADSPI_CCR_IMODE | QUADSPI_CCR_DMODE |
                      QUADSPI_CCR_ADMODE );
  QUADSPI->CCR |= ( 3 << QUADSPI_CCR_FMODE_Pos |
                    3 << QUADSPI_CCR_ADMODE_Pos |
                    3 << QUADSPI_CCR_DMODE_Pos |
                    1 << QUADSPI_CCR_IMODE_Pos |
                    0xEB << QUADSPI_CCR_INSTRUCTION_Pos |
                    6 << QUADSPI_CCR_DCYC_Pos );
  QUADSPI->CR  |=  ( QUADSPI_CR_EN );

  // Add a dummy cycle; if memory-mapped access is attempted
  // immediately after enabling the peripheral, it seems to fail.
  // I'm not sure why, but adding one nop instruction seems to fix it.
  __asm( "NOP" );

  // Print a dot to indicate control is passing to the kernel.
  UART4->TDR = '.';

  // Call the Linux kernel.
  void (*kernel)(uint32_t reserved, uint32_t mach, uint32_t dt) = (void (*)(uint32_t, uint32_t, uint32_t))(0x90000000 | 1);
  kernel(0, ~0UL, 0x08100000);

  // (Should never be reached.)
  while( 1 ) {};
  return 0;
}

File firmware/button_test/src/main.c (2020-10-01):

// Device header file.
#include "stm32h7xx.h"
// Standard library includes.
#include <string.h>
#include <stdio.h>
#include <stdlib.h>

extern uint32_t _sidata, _sdata, _edata, _sbss, _ebss, _siitcm, _sidtcm, _sitcm, _sdtcm, _eitcm, _edtcm, _estack;

// Core system clock speed.
uint32_t SystemCoreClock = 64000000;
// Global systick counter.
volatile uint32_t systick = 0;

// Reset handler: set the stack pointer and branch to main().
__attribute__( ( naked ) ) void reset_handler( void ) {
  // Set the stack pointer to the 'end of stack' value.
  __asm__( "LDR r0, =_estack\n\t"
           "MOV sp, r0" );
  // Branch to main().
  __asm__( "B main" );
}

// Interrupt handler for EXTI13.
void EXTI15_10_IRQn_handler( void ) {
  if ( EXTI->PR1 & ( 1 << 13 ) ) {
    // Acknowledge the interrupt.
    EXTI->PR1 |= ( 1 << 13 );
    // Toggle LED pins.
    GPIOC->ODR ^=  ( ( 1 << 6 ) | ( 1 << 7 ) );
    GPIOD->ODR ^=  ( 1 << 12 );
  }
}

/**
 * Main program.
 */
int main( void ) {
  // TODO: Enable SRAM1, SRAM2, SRAM3.
  // Enable GPIOC, GPIOD, SYSCFG peripherals.
  RCC->AHB4ENR  |=  ( RCC_AHB4ENR_GPIOCEN |
                      RCC_AHB4ENR_GPIODEN );
  RCC->APB4ENR  |=  ( RCC_APB4ENR_SYSCFGEN );

  // Copy initialized data from .sidata (Flash) to .data (RAM)
  memcpy( &_sdata, &_sidata, ( ( void* )&_edata - ( void* )&_sdata ) );
  memcpy( &_sitcm, &_siitcm, ( ( void* )&_eitcm - ( void* )&_sitcm ) );
  memcpy( &_sdtcm, &_sidtcm, ( ( void* )&_edtcm - ( void* )&_sdtcm ) );
  // Clear the .bss section in RAM.
  memset( &_sbss, 0x00, ( ( void* )&_ebss - ( void* )&_sbss ) );

  // Enable floating-point unit.
  SCB->CPACR    |=  ( 0xF << 20 );

  // Set LED pins (C6, C7, D12) to push-pull output mode.
  GPIOC->MODER  &= ~( ( 3 << ( 6 * 2 ) ) | ( 3 << ( 7 * 2 ) ) );
  GPIOD->MODER  &= ~( 3 << ( 12 * 2 ) );
  GPIOC->MODER  |=  ( ( 1 << ( 6 * 2 ) ) | ( 1 << ( 7 * 2 ) ) );
  GPIOD->MODER  |=  ( 1 << ( 12 * 2 ) );
  // Configure button pin (C13) for a falling-edge input.
  GPIOC->MODER  &= ~( 3 << ( 13 * 2 ) );
  GPIOC->PUPDR  |=  ( 1 << ( 13 * 2 ) );
  SYSCFG->EXTICR[ 3 ] |=  ( SYSCFG_EXTICR4_EXTI13_PC );
  EXTI->IMR1 |=  ( 1 << 13 );
  EXTI->RTSR1 &= ~( 1 << 13 );
  EXTI->FTSR1 |=  ( 1 << 13 );
  EXTI->PR1 |= ( 1 << 13 );

  // Pull LED3 high, LED1 / LED2 low.
  GPIOC->ODR    &= ~( 1 << 6 );
  GPIOC->ODR    |=  ( 1 << 7 );
  GPIOD->ODR    &= ~( 1 << 12 );

  // Enable the EXTI10-15 interrupt handler.
  // Use 4 bits for 'priority' and 0 bits for 'subpriority'.
  NVIC_SetPriorityGrouping( 0 );
  // Enable the EXTI0 interrupt.
  uint32_t btn_pri_encoding = NVIC_EncodePriority( 0, 3, 0 );
  NVIC_SetPriority( EXTI15_10_IRQn, btn_pri_encoding );
  NVIC_EnableIRQ( EXTI15_10_IRQn );

  // Done; wait.
  while( 1 ) { __WFI(); }
  return 0; // lol
}

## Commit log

2020-10-01 Initial project files: rev0.
    [stm32_linux.kicad_pcb, stm32_linux.sch]
2020-10-01 Add common supporting files for test firmwares.
    [stlink.cfg, stm32h7x.cfg, stm32h7x_dual_bank.cfg]
2020-10-01 Add LED test firmware
2020-10-01 Add button test firmware
2020-10-01 Add UART test program.
2020-10-01 Add WIP Linux bootloader for the board.
2020-10-01 Add renders of the board top / bottom
2020-10-01 Readme: add a couple of specific issues with the design
